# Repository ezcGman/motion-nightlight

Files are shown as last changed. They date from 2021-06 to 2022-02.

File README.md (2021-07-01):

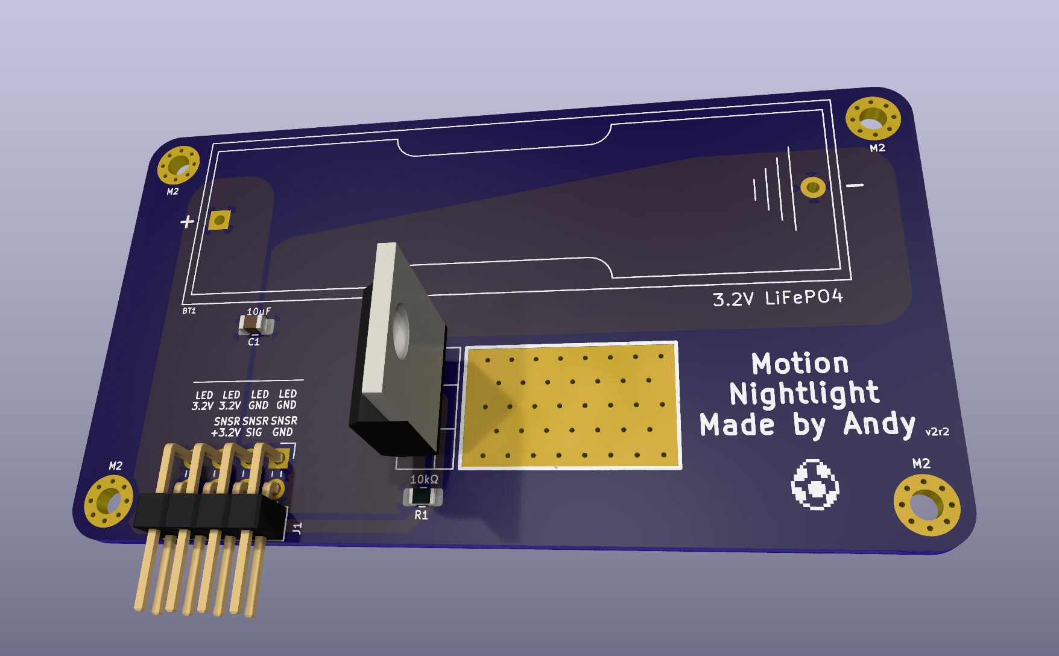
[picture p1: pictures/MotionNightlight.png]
How it looks at night


# Motion Nightlight
This is one of my first self designed PCBs in KiCad. It's a very simple circuit which can be utilized to create a motion nightlight with a few low power LED strips. See some examples at the bottom.

## Credits
Shoutout to Quindor from QuinLED.info, the LED master himself. He tought me a lot about KiCad, PCB design and some more electrical engineering fundamentals! While I'm still miles away from being perfect, with his help I really feel confident in what I'm doing here!

## KiCad dependencies
It might happen that KiCad is missing my custom footprints. You can find and download them here and then add them to KiCad: https://github.com/ezcGman/andys-footprints

## Parts list
All these parts can be easily found on AliExpress (except the PCBs ;) ):

- 1x The PCB in this folder, printed e.g. at PCBWay
- 1x 3.2V LiFePO4 battery in AA form factor
- 1x AA battery holder for THT mounting
- The HC-SR501 PIR sensor. And because this also would act at day time, we also need:
- An LDR, a light-dependent resistor, which can be installed into the HC-SR501 to make it only act at night time. See that great video of Clive: https://www.youtube.com/watch?v=2dxhbXHYEG0
- 1x MOSFET. Probably most FETs (ha ha, MOSt FETs... ha ha) are fine, just pay attention that the thermal pad is connected to **drain**, as the MOSFET bed on the PCB is connected to drain! But I suggest the IRL3803 which has perfect specs for this application:
  - Max Drain-Source Voltage of 30V
  - Gate Threshold Voltage already of 1V
- 1x 0805 SMD capacitor of 10µF or bigger. But 0805 SMD caps are usually limited to ~40µF. So whatever u have around
- 1x 0805 SMD resistor of 10kΩ
- 4x 2.54mm double row pin headers. I chose angled headers, as it makes the whole thing more flat, so you can hide it behind something

## Tools list
### Required
- A soldering iron
- Soldering tin

### Optional
- For SMD components:
  - A hot air soldering/reflow station. However, it's only two and u have space around them, so they can be done with a soldering iron. Also the MOSFET can be technically soldered with an iron.
  - Solder paste
  - Tweezers

# Example installation:
How it looks at night
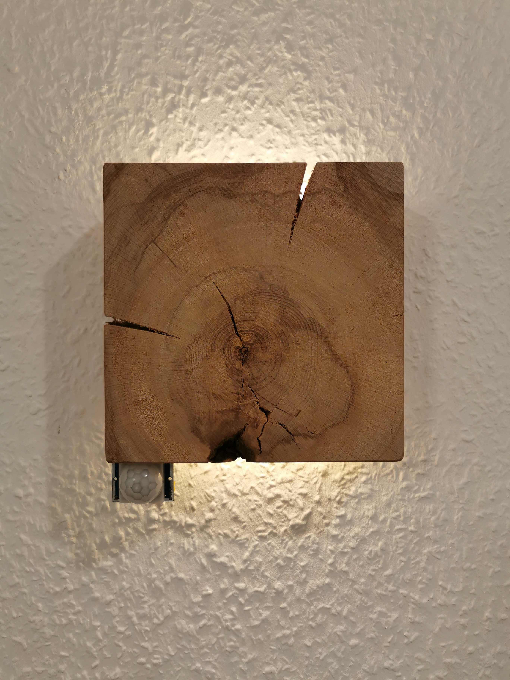
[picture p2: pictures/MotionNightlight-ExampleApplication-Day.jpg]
How it looks at day time

Assembled PCB

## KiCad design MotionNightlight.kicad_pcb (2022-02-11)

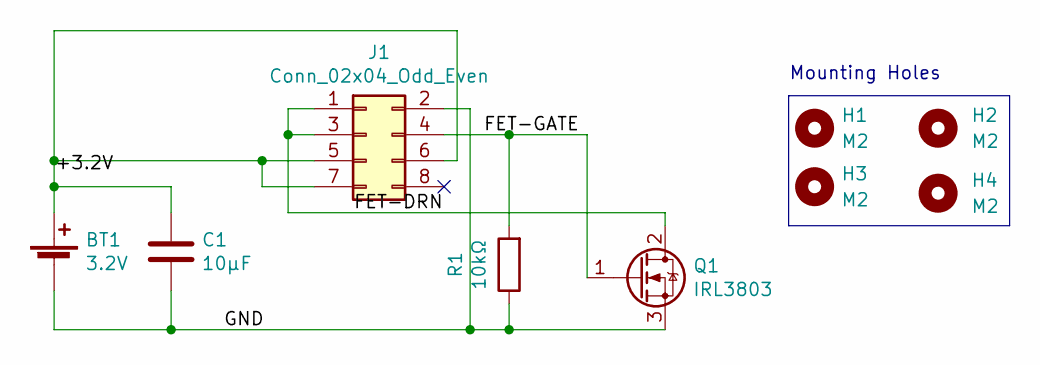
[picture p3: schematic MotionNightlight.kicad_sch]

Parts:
BT1: 3.2V; BatteryHolder_Keystone_2460_1xAA-removed-holes
C1: 10µF; C_0805_2012Metric_Pad1.18x1.45mm_HandSolder
H1, H2, H3, H4: M2; MountingHole_2.2mm_M2_Pad_Via
J1: Conn_02x04_Odd_Even; PinHeader_2x04_P2.54mm_Horizontal-Less-SilkScreen
Q1: IRL3803; TO-220-3_Vertical
R1: 10kΩ; R_0805_2012Metric_Pad1.20x1.40mm_HandSolder

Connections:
/+3.2V: BT1.1 (+), C1.1, J1.5, J1.6, J1.7
/FET-DRN: J1.1, J1.3, Q1.2 (D)
/FET-GATE: J1.4, Q1.1 (G), R1.2
/GND: BT1.2 (-), C1.2, J1.2, Q1.3 (S), R1.1

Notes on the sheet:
Mounting Holes

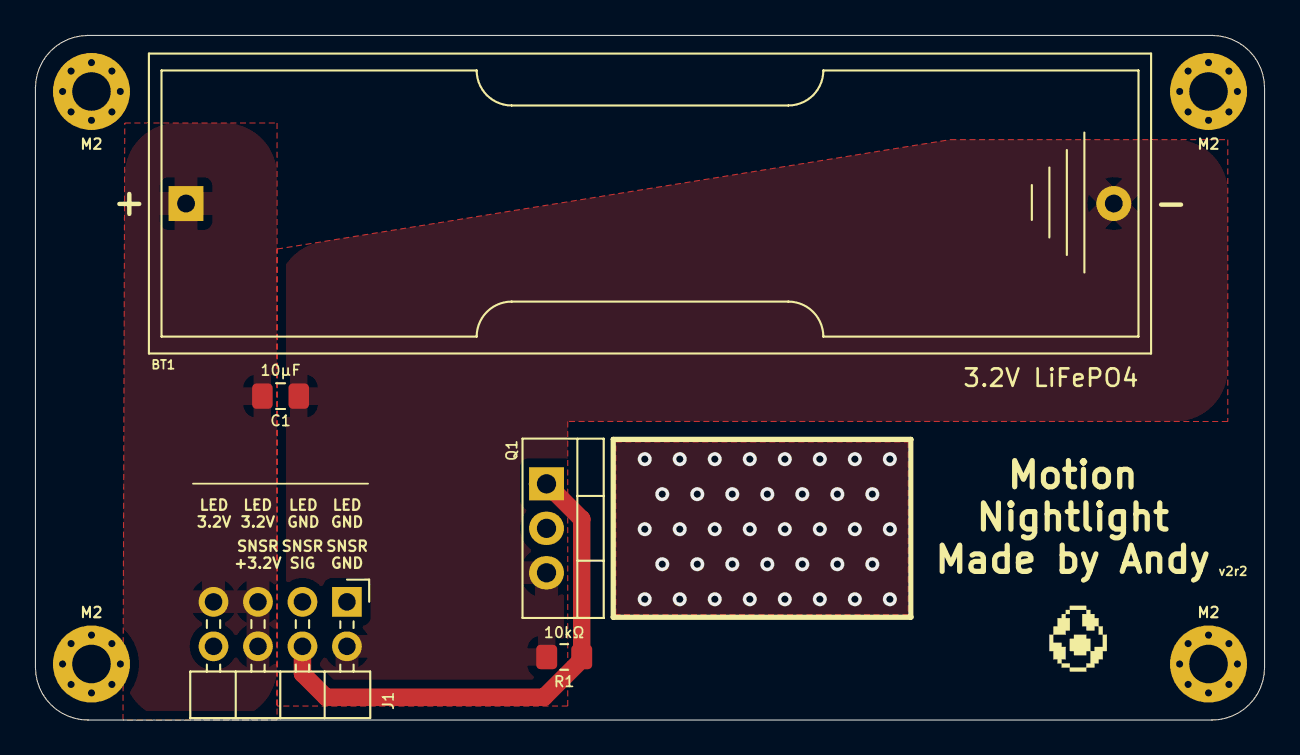
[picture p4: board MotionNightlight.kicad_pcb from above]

Board: 2 copper layers, 70.2 x 39.1 mm, 9 parts (0 on the bottom side), 4 nets.
